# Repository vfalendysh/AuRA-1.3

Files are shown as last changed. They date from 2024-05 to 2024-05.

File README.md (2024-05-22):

# AuRA 1.3 Rotary Assist Film Developing Machine

## READ THIS FIRST
This project is the next iteration of the AuRA Film Developing Machine.
Original machine was introduced on the Kickstarter back in 2021.

https://www.kickstarter.com/projects/vfalendysh/aura-rotary-assist-film-developing-machine

v1.2 review by Alex Luyckx: https://www.youtube.com/watch?v=DZNfe24eHN0

I'm trying my best to keep this project alive for the benefit of the Film Photography community.

### PLEASE NOTE: 
- Everything provided AS IS, without any warranties.
- Non-commercial private use only. I reserve the right for the commercial distribution and use. 
- Zero liability - you do it at your own risk. I'm not liable for any damages related to this project.
- If you continue with this project it means that you read and agree with the above statements.

## LICENSE
Shared under Attribution-NonCommercial-ShareAlike 4.0 International License

https://creativecommons.org/licenses/by-nc-sa/4.0/deed.en

## PURCHASE YOUR AuRA
https://aurafd.company.site/

## Electronics Assembly Manual (WIP)
https://docs.google.com/document/d/1hErU2MmGirhdWFpWhWet4WLlM-BJHZemsq4ywI-r1ss/edit?usp=sharing

## Operations Manual
https://docs.google.com/document/d/11cLEZ-TlUOUsFuLOAkJhnijDMngBIQ9VhE78JiG_ncQ/edit?usp=sharing

## Questions?
Please ask here: https://www.facebook.com/groups/195994281887859

## Changes between 1.2 and 1.3
### Firmware
- Max dev. time increased to 90 minutes.
- Changed tanks captions in "Settings" menu.
- Enabled demo mode by default.

### Mechanical
- Main ball bearings are moved on the outside of the constaining bodies and now fixed on both sides.
- No need for retaining rings (no lathe work required) - replaced with shaft collars.
- Increased main case size a little bit for better access.
- Boards are now easily removable if needed - they are placed on the platform and fixed with 2 screws only.
- No USB port on a side (may add latter uppon request).

## Bill Of Materials
Most of the componets can be purchase on Amazon or AliExpress. 

https://docs.google.com/spreadsheets/d/1RUYtAMMg844CDN_oNOtQVQ9Nui_DjjbX51vlC8axlfM/edit?usp=sharing

Please let me know if something is missing from the BOM or you have sourcing questions.

## 3d Printer Settings
All parts should be printed with the following settings:
- 0.4mm nozzle
- 4 perimeters
- 0.2mm layer height
- 5 top/bottom shells
- 60% geroid infill
- PETG plastic
- Colors you like
  
Please make sure that your printer is calibrated and prints with the hight dimmensional accuracy.
If rollers do not fit - try to print one by one resizing it by 0.2% increment.

## Firmware
- Put folders / files from the "Firmware/libs" folder into your local Arduino/libraries folder.
- Choose "Arduino Nano" board in Arduino IDE. Sometimes you may need to choose "old bootloader" verstion of the board.
- Open "firmware/aura13.ino" file.
- Compile / upload to the board.

If you have binary size issues - make sure that U8G2 library has size optimizations turned on. 
Check for more here: https://github.com/olikraus/u8g2/wiki/u8g2optimization

## Electronics
Wire / assembly diagram - WIP.

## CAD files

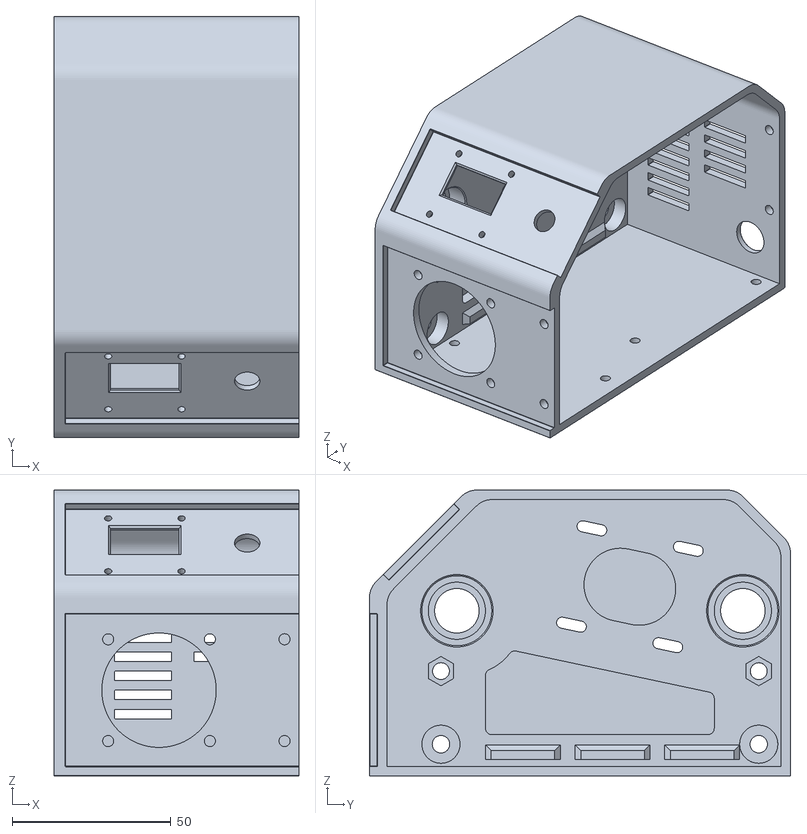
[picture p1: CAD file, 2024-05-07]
STL/Frame Main Case.stl
77.0 x 132.5 x 90.0

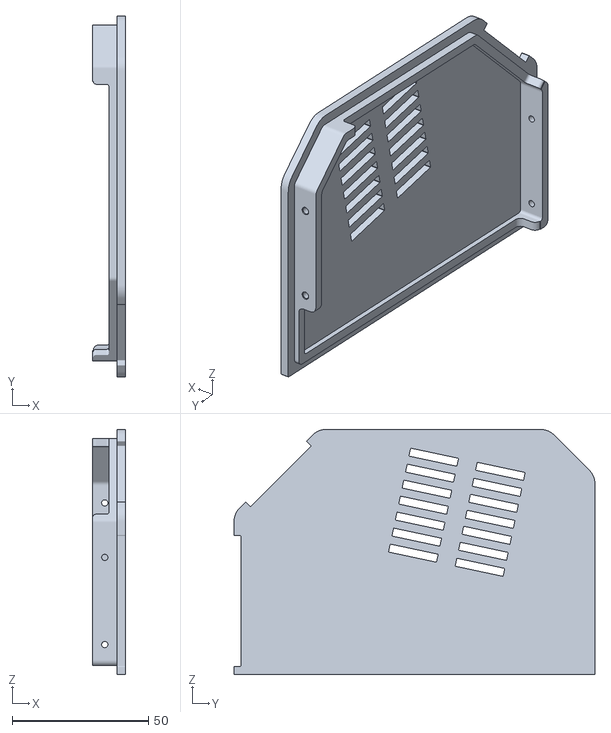
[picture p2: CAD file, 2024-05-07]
STL/Frame Main Case Side.stl
12.0 x 132.5 x 90.0

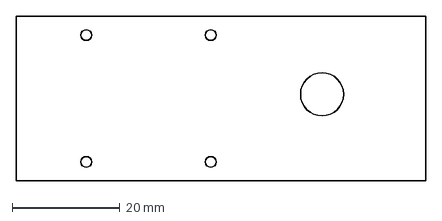
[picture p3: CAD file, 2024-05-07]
DXF/Screen Panel.dxf
76.0 x 30.5 mm

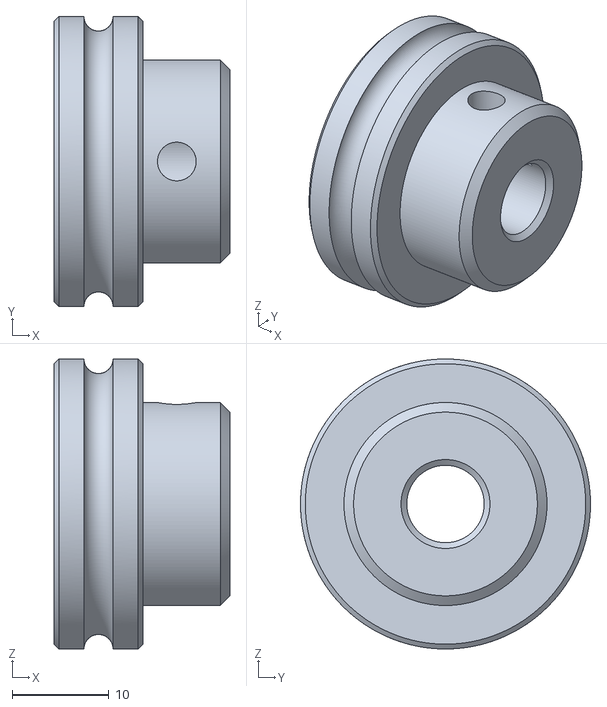
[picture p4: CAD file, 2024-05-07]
STL/Roller Soft Pad - 2x.stl
18.2 x 30.0 x 30.0

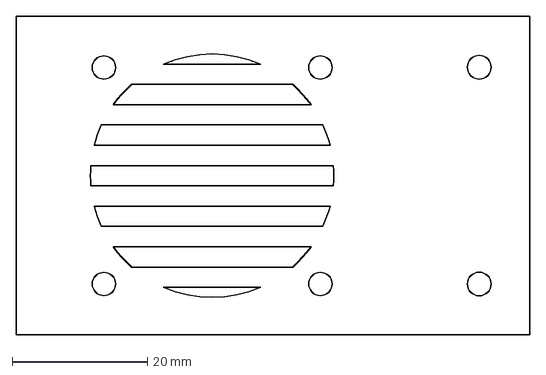
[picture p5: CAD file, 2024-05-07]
DXF/Fan Panel.dxf
76.0 x 47.1 mm

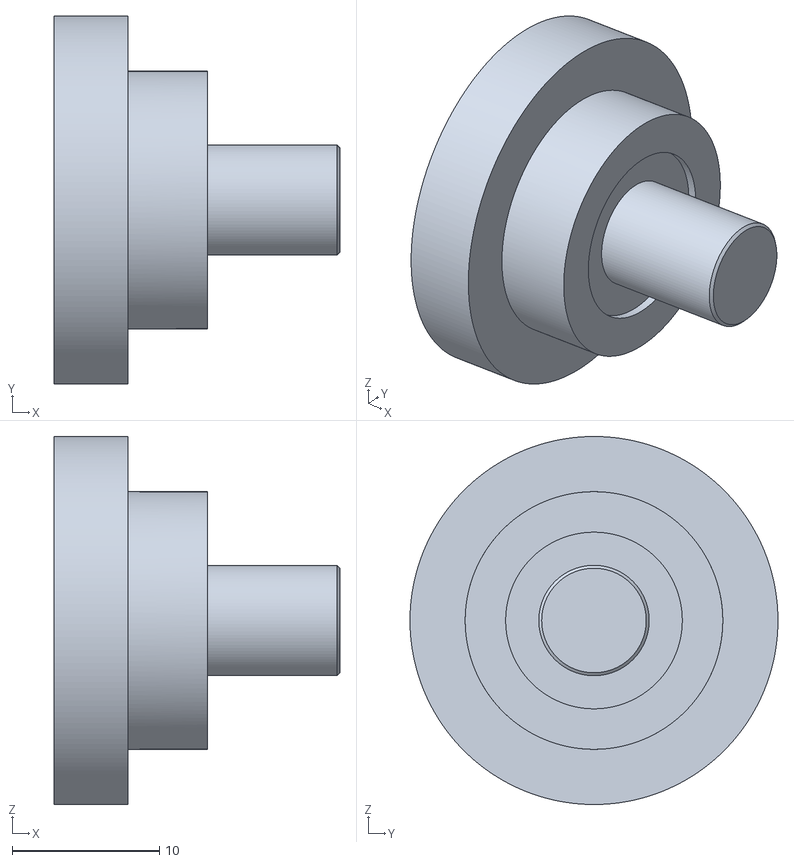
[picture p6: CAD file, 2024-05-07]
STL/Tool For Bearings.stl
19.4 x 25.0 x 25.0

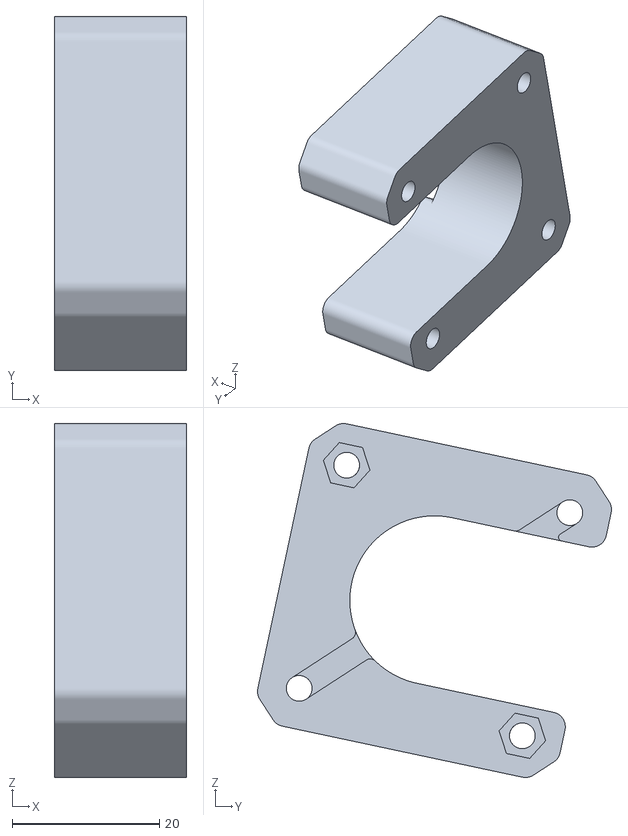
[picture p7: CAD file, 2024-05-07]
STL/Motor Base.stl
18.0 x 48.1 x 48.1

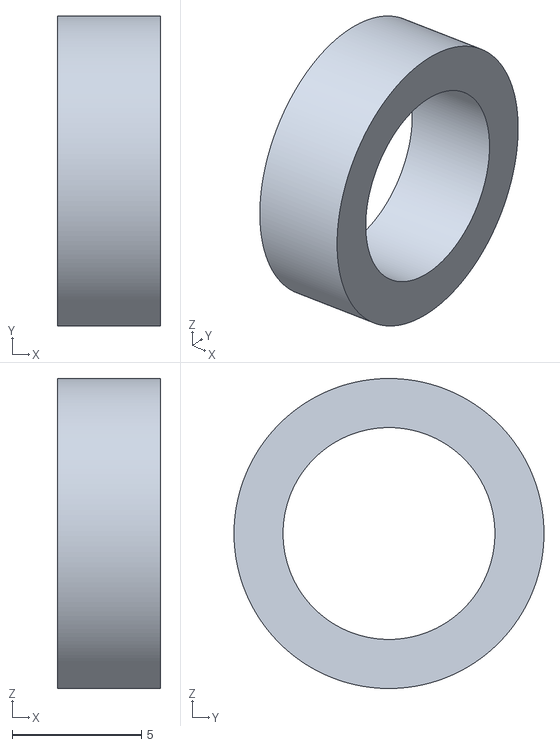
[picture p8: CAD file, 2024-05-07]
STL/Spacer 04mm - 2x.stl
4.00 x 12.0 x 12.0

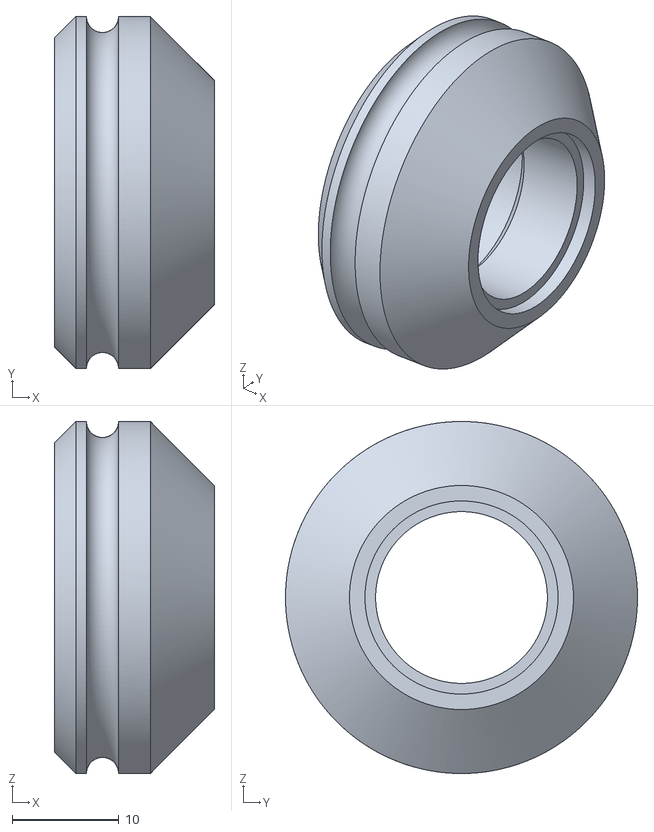
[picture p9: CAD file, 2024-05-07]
STL/Roller Paterson - 2x.stl
15.0 x 33.0 x 33.0

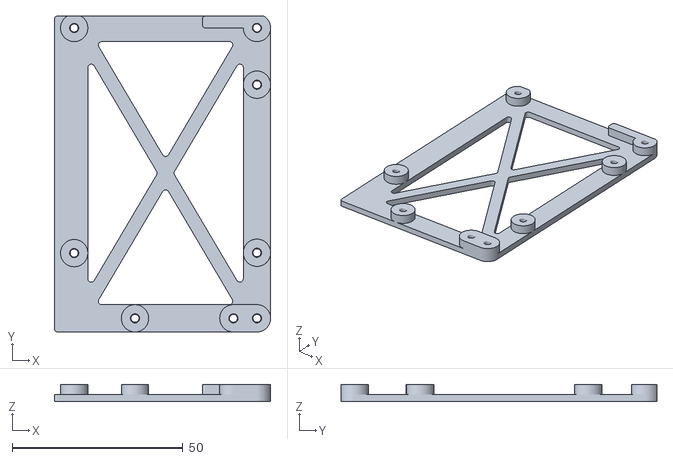
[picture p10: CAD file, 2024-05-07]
STL/Boards Base.stl
63.3 x 92.5 x 5.00

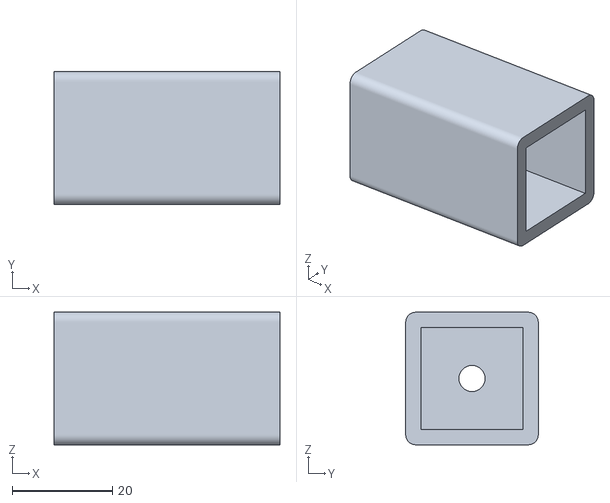
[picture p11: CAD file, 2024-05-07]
STL/Tool Extrusion Threading Guide.stl
45.0 x 26.4 x 26.4

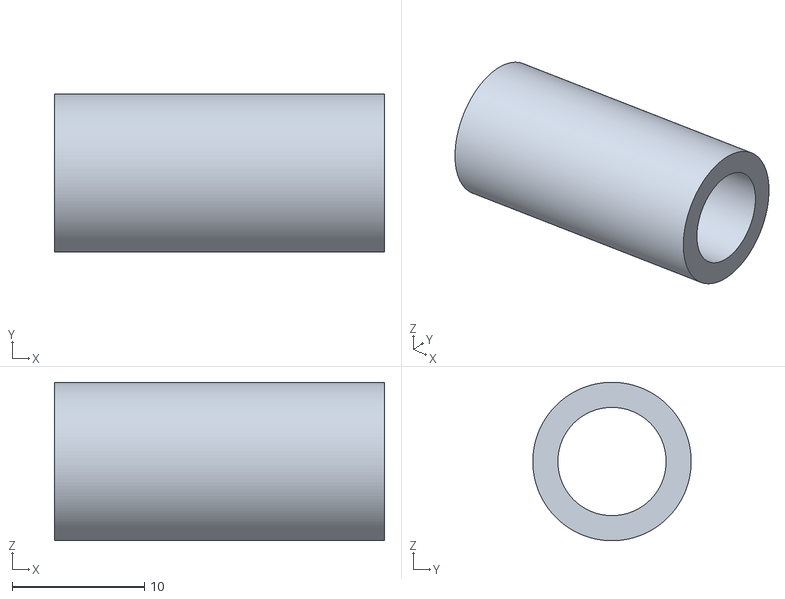
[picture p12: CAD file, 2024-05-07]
STL/Spacer 25mm - 2x.stl
25.0 x 12.0 x 12.0

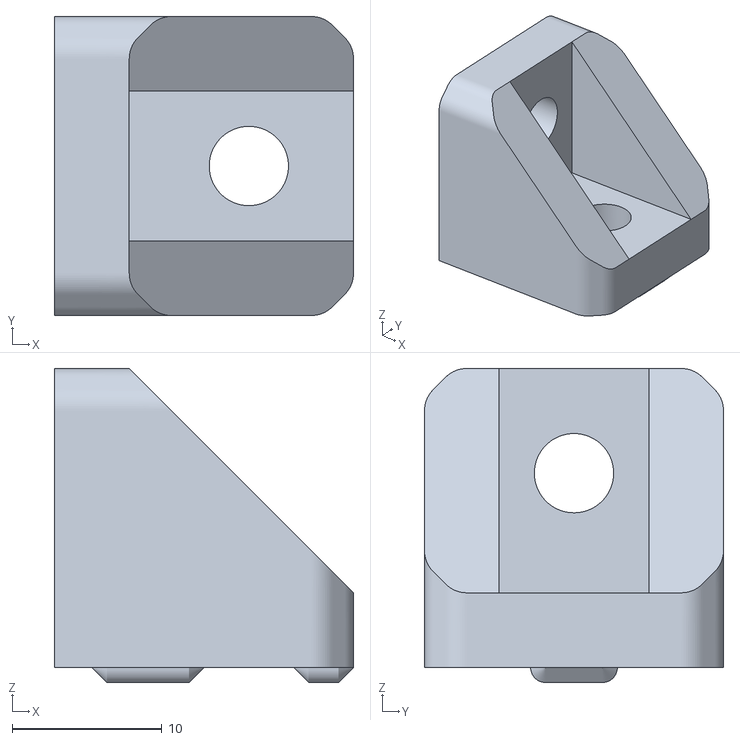
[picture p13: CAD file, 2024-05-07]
STL/Frame Corner Bracket - 4x.stl
20.0 x 20.0 x 21.0

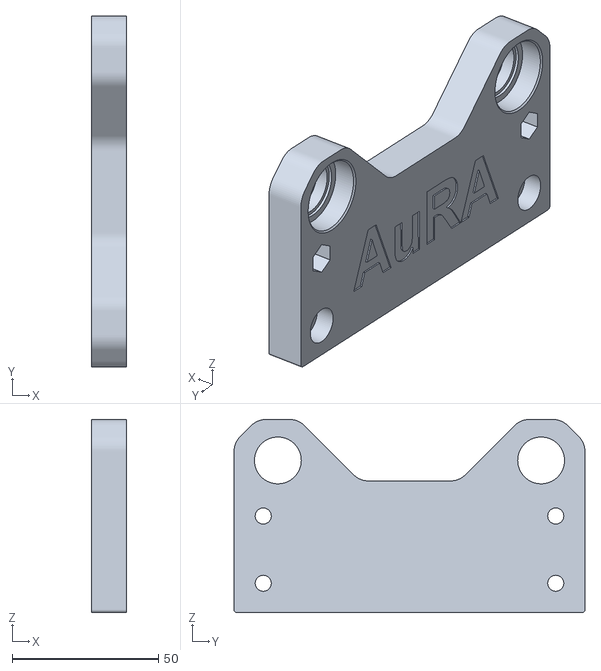
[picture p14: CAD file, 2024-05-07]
STL/Frame Drive Suppert Left.stl
12.0 x 120.0 x 66.0

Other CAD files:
STL/Spacer 12mm - 2x.stl
STL/Roller Jobo - 2x.stl
STL/Spacer 08mm - 2x.stl
STL/Roller Flat - 6x.stl
STL/Roller Nut Tool.stl

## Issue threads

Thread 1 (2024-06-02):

Missing Componenten Wiring Diagram

mherke, 2024-06-02:
Hello, are there any instructions on how to wire the electronic components? I found the documentation on GitHub, but it is still very incomplete.

...thanks for your support

Michael

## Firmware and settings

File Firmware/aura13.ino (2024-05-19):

#include <EEPROM.h>
#include <Rotary.h>
#include <U8g2lib.h>
#include "AccelStepper.h" 

// enables demo / test mode in settings menu. endlesly runs programs when enabled; 1 or 0
#define DEMO_AVAILABLE 1

// changes rotary encoder direction; 1 or -1
#define ENCODER_DIRECTION 1

// continuous must rotate counter clock when looking on a tank cap side
// set to -1 to invert or 1 to normal
#define MOTOR_DIRECTION -1

#include "Pins.h"
#include "Menus.h"

/**
 * Stepper
 */
AccelStepper stepper(1, PIN_MOTOR_STEP, PIN_MOTOR_DIR);

/**
 * Rotary encoder
 */
Rotary rotary = Rotary(PIN_ENC_A, PIN_ENC_B);

volatile boolean rotaryButtonUp = false;
volatile boolean rotaryButtonDown = false;
volatile boolean rotaryButtonPressed = false;
volatile boolean rotaryButtonLongPressed = false;
volatile boolean rotaryButtonWasPressed = false;
unsigned long rotaryButtonPressedMillis = 0;

/**
 * Machine state
 */
#define STATE_MENU 0
#define STATE_RUN 1
#define STATE_DONE 2
#define STATE_STOPPED 3

#define PROGRAMM_MODE_R1 MENU_ROOT_R1
#define PROGRAMM_MODE_R2 MENU_ROOT_R2
#define PROGRAMM_MODE_R3 MENU_ROOT_R3
#define PROGRAMM_MODE_R4 MENU_ROOT_R4
#define PROGRAMM_MODE_TIMER MENU_ROOT_TIMER

byte machineState = STATE_MENU;
bool presetSelected = false;

/**
 * Counters
 */
unsigned int finishedCount = 0; 
unsigned int interruptedCount = 0;

/**
 * Settings
 */
#define EEPROM_SETTINGS_SAVED 0
#define EEPROM_SETTINGS_SOUND 1
#define EEPROM_SETTINGS_TANK 2
#define EEPROM_SETTINGS_FINISHED_BYTE1 3
#define EEPROM_SETTINGS_FINISHED_BYTE0 4
#define EEPROM_SETTINGS_INTERRUPTED_BYTE1 5
#define EEPROM_SETTINGS_INTERRUPTED_BYTE0 6
#if (DEMO_AVAILABLE == 1)
  #define EEPROM_SETTINGS_DEMO 7
#endif  

// Preset settings
#define EEPROM_SETTINGS_PRESETS_OFFSET 10

#define PRESET_MODE 0
#define PRESET_MINUTES 1
#define PRESET_SECONDS 2
#define PRESET_SPEED 3

#define MAX_MINUTES 90

volatile byte presets[PRESETS_COUNT][PRESETS_SETTINGS_COUNT] = {
  {0, 10, 0, 50},
  {0, 10, 0, 50},
  {0, 10, 0, 50},
  {0, 10, 0, 50},
  {0, 10, 0, 50},
};

/**
 * Tanks
 */
#define TANK_MODEL_COUNT 3
#define TANK_J1500 0
#define TANK_J2500 1
#define TANK_P4 2

/**
 * Sound
 */
byte settingsSound = 1;
byte settingsTank = TANK_J1500;

/**
 * Demo / test mode
 */
#if (DEMO_AVAILABLE == 1)
  byte settingsDemo = 0;
#endif  

/**
 * Menus
 */
byte menuMode = MENU_MODE_ROOT;
int8_t menuPosition = 0;
int8_t menuPresetsPosition = 0;
int8_t menuSettingsPosition = 0;
int8_t menuSettingsPresetsPosition = 0;
byte programmMode = 0;

/**
 * Programm times in seconds
 */
int programmDurationSeconds = 300;
int programmTimeSeconds = 0;
int programmTimeLeftSeconds = programmDurationSeconds;

/**
 * Motor vars
 */
bool runMotor = false;
bool runMotorBackwards = false;
int  runMotorBackwardsSwitchTime = 0;
bool motorAccelerating = false;
bool slowDown = false;

#define MOTOR_SPEEDS_COUNT 12
byte motorSpeedIndex = 9;
byte motorRPMs[MOTOR_SPEEDS_COUNT] = {5, 10, 15, 20, 25, 30, 35, 40, 45, 50, 60, 75};

float motorSpeedMultipliers[TANK_MODEL_COUNT][MOTOR_SPEEDS_COUNT] = {
  // Jobo 1500
  {19, 19, 19, 19.25, 19.25, 19.5, 19.5, 19.5, 19.75, 20.0, 20.25, 20.5},

  // Jobo 2500
  {27, 27, 27, 27.34, 27.34, 27.69, 27.69, 27.69, 28.00, 28.4, 28.75, 29.1},

  // Paterson 4
  {21.0, 21.0, 21.5, 21.8, 22.0, 22.2, 22.2, 22.5, 22.7, 23.0, 23.0, 23.0}
};

int motorMaxSpeed;
int motorTargetSpeed;
float motorCurrentSpeed = 0;

float motorAcceleration = 0.2;
float motorDeceleration = 0.16;

/**
 * Screen
 */
U8G2_SSD1306_128X64_NONAME_2_HW_I2C u8g2(U8G2_R0, PIN_OLED_CLK, PIN_OLED_DAT);

/**
 * Setup
 */
void setup() {
  /**
   * Settings from memory
   */
  if (EEPROM.read(EEPROM_SETTINGS_SAVED) == 1) {
    settingsSound = EEPROM.read(EEPROM_SETTINGS_SOUND);
    
    #if (DEMO_AVAILABLE == 1)
      settingsDemo = EEPROM.read(EEPROM_SETTINGS_DEMO);     
    #endif
      
    settingsTank = EEPROM.read(EEPROM_SETTINGS_TANK);

    finishedCount = EEPROM.read(EEPROM_SETTINGS_FINISHED_BYTE1) * 256 + EEPROM.read(EEPROM_SETTINGS_FINISHED_BYTE0);
    interruptedCount = EEPROM.read(EEPROM_SETTINGS_INTERRUPTED_BYTE1) * 256 + EEPROM.read(EEPROM_SETTINGS_INTERRUPTED_BYTE0);

    for (byte i = 0; i < PRESETS_COUNT; i++) {
      presets[i][PRESET_MODE] = EEPROM.read(EEPROM_SETTINGS_PRESETS_OFFSET + i * PRESETS_SETTINGS_COUNT + PRESET_MODE);
      presets[i][PRESET_MINUTES] = EEPROM.read(EEPROM_SETTINGS_PRESETS_OFFSET + i * PRESETS_SETTINGS_COUNT + PRESET_MINUTES);
      presets[i][PRESET_SECONDS] = EEPROM.read(EEPROM_SETTINGS_PRESETS_OFFSET + i * PRESETS_SETTINGS_COUNT + PRESET_SECONDS);
      presets[i][PRESET_SPEED] = EEPROM.read(EEPROM_SETTINGS_PRESETS_OFFSET + i * PRESETS_SETTINGS_COUNT + PRESET_SPEED);
    }
  }

  // check settings
  if (settingsSound > 1) settingsSound = 1;
  
  #if (DEMO_AVAILABLE == 1)
    if (settingsDemo > 1) settingsDemo = 1;
  #endif
  
  if (settingsTank >= TANK_MODEL_COUNT) settingsTank = TANK_J1500;
  if (finishedCount > 65530) finishedCount = 0;
  if (interruptedCount == 65530) interruptedCount = 0;
  
  for (byte i = 0; i < PRESETS_COUNT; i++) {
    if (presets[i][PRESET_MODE] > 2) presets[i][PRESET_MODE] = 0;
    if (presets[i][PRESET_MINUTES] > MAX_MINUTES) {
      presets[i][PRESET_MINUTES] = 10;
      presets[i][PRESET_SECONDS] = 0;
    }
    if (presets[i][PRESET_SECONDS] >= 60) presets[i][PRESET_SECONDS] = 0;

    if (presets[i][PRESET_MINUTES] * MAX_MINUTES + presets[i][PRESET_SECONDS] < 60) {
      presets[i][PRESET_MINUTES] = 10;
      presets[i][PRESET_SECONDS] = 0;
    }

    if (presets[i][PRESET_SPEED] >= MOTOR_SPEEDS_COUNT) presets[i][PRESET_SPEED] = motorSpeedIndex;
  }

  motorMaxSpeed = 3000;
  motorTargetSpeed = motorRPMs[motorSpeedIndex] * motorSpeedMultipliers[settingsTank][motorSpeedIndex];

  /**
   * Stepper setup
   */
  stepper.setMaxSpeed(motorMaxSpeed);
  stepper.setEnablePin(PIN_MOTOR_EN);
  stepper.setPinsInverted(false, false, true);

  /**
   * Buzzer
   */
  pinMode(PIN_BUZZER, OUTPUT);

  /**
   * Fan 
   */
  pinMode(PIN_FAN, OUTPUT);
  
  /**
   * Rotary encoder
   */
  pinMode(PIN_ENC_C, INPUT_PULLUP);

  u8g2.begin();
  u8g2.setFontPosTop();
  
  digitalWrite(PIN_FAN, HIGH);
  displayIntro();
  delay(2500);  
  digitalWrite(PIN_FAN, LOW);
  
  updateScreen();

  /**
   * Time interruprs
   */
  // TIMER 1 for interrupt frequency 16000 Hz:
  cli(); // stop interrupts
  TCCR1A = 0; // set entire TCCR1A register to 0
  TCCR1B = 0; // same for TCCR1B
  TCNT1  = 0; // initialize counter value to 0
  // set compare match register for 16000 Hz increments
  OCR1A = 999; // = 16000000 / (1 * 16000) - 1 (must be <65536)
  // turn on CTC mode
  TCCR1B |= (1 << WGM12);
  // Set CS12, CS11 and CS10 bits for 1 prescaler
  TCCR1B |= (0 << CS12) | (0 << CS11) | (1 << CS10);
  // enable timer compare interrupt
  TIMSK1 |= (1 << OCIE1A);
  sei(); // allow interrupts
}

/**
 * Runs motor on timer interrupt
 * timer1 interrupt 8kHz toggles pin 9
 */
ISR(TIMER1_COMPA_vect){
  //generates pulse wave of frequency 8kHz/2 = 4kHz (takes two cycles for full wave- toggle high then toggle low)
  if (machineState == STATE_RUN && runMotor) {
    stepper.runSpeed();
  }
}

/**
 * Main loop
 */
void loop() {

  if (machineState == STATE_MENU) {
    handleRotaryEncoder();
  
    if (rotaryButtonPressed) {
      handleMenuSelectActions();
      if (machineState == STATE_MENU) updateScreen();
      rotaryButtonPressed = false;
      delay(200);
    } else if (rotaryButtonLongPressed) {
      handleMenuBackActions();
      if (machineState == STATE_MENU) updateScreen();
      rotaryButtonLongPressed = false;
      delay(200);
    } else if (rotaryButtonUp || rotaryButtonDown) {
      handleMenuScrollActions();
      updateScreen();
      rotaryButtonUp = rotaryButtonDown = false;
    }
   
  } else if (machineState == STATE_RUN) {
    runProgramm();
  } else if (machineState == STATE_DONE || machineState == STATE_STOPPED) {
    
    handleRotaryEncoder();
    
    if (rotaryButtonPressed || rotaryButtonLongPressed || rotaryButtonUp || rotaryButtonDown) {
      if (presetSelected) {
        machineState = STATE_MENU;
        menuMode = MENU_MODE_PRESETS;
        //menuPresetsPosition++;
        //if (menuPresetsPosition >= PRESETS_COUNT) menuPresetsPosition = 0;
      } else {
        machineState = STATE_MENU;
        menuMode = MENU_MODE_ROOT;
      }
      updateScreen();
      rotaryButtonPressed = rotaryButtonLongPressed = rotaryButtonUp = rotaryButtonDown = false;
      delay(200);
    }
  }
}

/**
 * Get speed by index
 */
int getSpeedByIndex(byte i) {
  return motorRPMs[i] * motorSpeedMultipliers[settingsTank][i];
}

/**
 * Get deceleration coeficient by index
 */
float getAccelerationByIndex(byte i) {
  return motorRPMs[i] / (settingsTank == TANK_J1500 ? 175.0 : (settingsTank == TANK_J2500 ? 125.0 : 150.0)); // bigger number - smaller steps, slower acceleration
}

/**
 * Get deceleration coeficient by index
 */
float getDecelerationByIndex(byte i) {
  return motorRPMs[i] / (settingsTank == TANK_J1500 ? 200.0 : (settingsTank == TANK_J2500 ? 125.0 : 150.0)); // bigger number - smaller steps, slower deceleration
}

/**
 * Beep
 */
void beep(int d) {
  tone(PIN_BUZZER, 3520);
  delay(d);
  noTone(PIN_BUZZER);
}

/**
 * Run programm
 */
void runProgramm() {
  unsigned long programmStartMillis = millis();
  unsigned long programmLeftMillis = programmDurationSeconds * 1000L;
  unsigned long programmEndMillis = programmStartMillis + programmLeftMillis;
  unsigned long lastScreenUpdateSecond;

  runMotorBackwards = false;
  runMotorBackwardsSwitchTime = 0;
  runMotor = false;
  slowDown = false;
  programmTimeSeconds = 0;
  lastScreenUpdateSecond = 1;

  programmTimeLeftSeconds = programmDurationSeconds;
 
  if (programmMode != PROGRAMM_MODE_TIMER) {

    if ((settingsTank == TANK_J2500) && (motorSpeedIndex > MOTOR_SPEEDS_COUNT - 3)) motorSpeedIndex = MOTOR_SPEEDS_COUNT - 3; // 50 max
    
    motorCurrentSpeed = 0;
    motorTargetSpeed = getSpeedByIndex(motorSpeedIndex);
    stepper.enableOutputs();
    setMotorState();

    // run fun only when motor is moving
    digitalWrite(PIN_FAN, HIGH);
  }

  updateScreen();
  
  for (;;) {
    
    unsigned long currentMillis = millis();

    programmTimeLeftSeconds = programmLeftMillis / 1000L;
    programmTimeSeconds = programmDurationSeconds - programmTimeLeftSeconds;
    
    if (currentMillis > programmEndMillis) {
      
      if (programmMode != PROGRAMM_MODE_TIMER) {
        runMotor = false;
        digitalWrite(PIN_FAN, LOW);
        stepper.disableOutputs();
      }

      finishedCount++;
      EEPROM.write(EEPROM_SETTINGS_FINISHED_BYTE1, finishedCount >> 8);
      EEPROM.write(EEPROM_SETTINGS_FINISHED_BYTE0, finishedCount % 256);
      
      machineState = STATE_DONE;
      updateScreen();

      if (settingsSound == 1) {
        beep(1000);
        delay(100);
        beep(1000);
      }

      #if (DEMO_AVAILABLE == 1)
        if (settingsDemo == 1) {
          delay(1000);
          machineState = STATE_RUN;
          programmTimeLeftSeconds = programmDurationSeconds;
          programmTimeSeconds = 0;
          programmMode++;
          if (programmMode >= PROGRAMM_MODE_TIMER) {
            programmMode = PROGRAMM_MODE_R1; 
          }
          updateScreen();
        }  
      #endif   
      
      break;
    }
    
    programmLeftMillis = programmEndMillis - currentMillis;

    handleRotaryEncoder();

    if (programmMode != PROGRAMM_MODE_TIMER) {
      /**
       * Increase RPM
       */
      if (rotaryButtonUp) {
        if (motorSpeedIndex < MOTOR_SPEEDS_COUNT - 1) {
          motorSpeedIndex += 1;

          if ((settingsTank == TANK_J2500) && (motorSpeedIndex > MOTOR_SPEEDS_COUNT - 3)) motorSpeedIndex = MOTOR_SPEEDS_COUNT - 3; // 50 max
          
          motorTargetSpeed = getSpeedByIndex(motorSpeedIndex);
          updateScreen();
        }
        rotaryButtonUp = false;
      }
  
      /**
       * Decrease RPM
       */
      if (rotaryButtonDown) {
        if (motorSpeedIndex > 0) {
          motorSpeedIndex -= 1;
          motorTargetSpeed = getSpeedByIndex(motorSpeedIndex);
          updateScreen();
        }
        rotaryButtonDown = false;
      }
  
      setMotorState();
    }

    /**
     * Stop programm
     */
    if (rotaryButtonLongPressed) {
      runMotor = false;
      digitalWrite(PIN_FAN, LOW);
      stepper.disableOutputs();
      machineState = STATE_STOPPED;
      
      interruptedCount++;
      EEPROM.write(EEPROM_SETTINGS_INTERRUPTED_BYTE1, interruptedCount >> 8);
      EEPROM.write(EEPROM_SETTINGS_INTERRUPTED_BYTE0, interruptedCount % 256);
      
      updateScreen();
      rotaryButtonLongPressed = false;
      delay(200);
      break; 
    }

    /**
     * Check programm times
     */
    if (programmTimeSeconds != lastScreenUpdateSecond) {
      
      updateScreen();
      
      lastScreenUpdateSecond = programmTimeSeconds;

      if (settingsSound == 1) {
        if (programmTimeLeftSeconds == 60) {
          beep(100);
        } else if (programmTimeLeftSeconds == 30) {
          beep(100); delay(100); beep(100);
        }
      }
    }
  }
}

void setMotorStateAccelR2R3R4() {
  if (motorCurrentSpeed < motorTargetSpeed) {
    motorCurrentSpeed += getAccelerationByIndex(motorSpeedIndex);
    if (motorCurrentSpeed > motorTargetSpeed) motorCurrentSpeed = motorTargetSpeed;
  } else if (motorCurrentSpeed > motorTargetSpeed) {
    motorCurrentSpeed -= getDecelerationByIndex(motorSpeedIndex);
    if (motorCurrentSpeed < 0) motorCurrentSpeed = 0;
  }
}

/**
 * Set motor state
 */
void setMotorState() {

  int sec = programmTimeSeconds % 60;
  
  if (programmTimeLeftSeconds < 2) {
    slowDown = true;
    motorTargetSpeed = 0;
  }

  switch (programmMode) {
    /**
     * Easy
     */
    case PROGRAMM_MODE_R1: {
      byte mod = sec % 30;
      if (programmTimeSeconds <= 30) {
        // fast first 30 seconds
        motorTargetSpeed = getSpeedByIndex(motorSpeedIndex);
      } else {
        motorTargetSpeed = getSpeedByIndex(mod >= 25 ? motorSpeedIndex : motorSpeedIndex / 5);
          if (mod == 24) motorTargetSpeed = 0;
          if ((mod == 25) && (programmTimeSeconds - runMotorBackwardsSwitchTime > 0)) {
            runMotorBackwards = !runMotorBackwards;
            runMotorBackwardsSwitchTime = programmTimeSeconds;
          }
      }
      
      if (motorCurrentSpeed < motorTargetSpeed) {
        // accelerate
        motorCurrentSpeed += getAccelerationByIndex(motorSpeedIndex);
        if (motorCurrentSpeed > motorTargetSpeed) motorCurrentSpeed = motorTargetSpeed;
      } else if (motorCurrentSpeed > motorTargetSpeed && motorCurrentSpeed > 0) {
        // decelerate
        motorCurrentSpeed -= motorTargetSpeed == 0 ? getDecelerationByIndex(0) : getDecelerationByIndex(motorSpeedIndex);
        if (motorCurrentSpeed < 0) motorCurrentSpeed = 0;
      }

      stepper.setSpeed((runMotorBackwards ? -1 : 1) * motorCurrentSpeed * MOTOR_DIRECTION);
      
      runMotor = true;
        
      break;
    }

    /**
     * Continuous
     */
    case PROGRAMM_MODE_R2: {
     
      setMotorStateAccelR2R3R4();
      stepper.setSpeed(motorCurrentSpeed * MOTOR_DIRECTION);
      
      runMotor = true;
        
      break;
    }

    /**
     * Oscilation 1:1
     */
    case PROGRAMM_MODE_R3: {
      byte mod = sec % 15;

      motorTargetSpeed = slowDown ? 0 : (mod < 8 ? (mod > 6 ? 0 : getSpeedByIndex(motorSpeedIndex)) : (mod > 13 ? 0 : getSpeedByIndex(motorSpeedIndex)));
      
      setMotorStateAccelR2R3R4();
      stepper.setSpeed((mod < 8 ? motorCurrentSpeed : - motorCurrentSpeed) * MOTOR_DIRECTION);
      
      runMotor = true;
            
      break;
    }
    
    /**
     * Progress 1:5
     */
    case PROGRAMM_MODE_R4: {
      byte mod = sec % 10;

      motorTargetSpeed = slowDown ? 0 : (mod < 7 ? (mod > 5 ? 0 : getSpeedByIndex(motorSpeedIndex)) : (mod > 8 ? 0 : getSpeedByIndex(motorSpeedIndex)));
     
      setMotorStateAccelR2R3R4(); 
      stepper.setSpeed((mod < 7 ? motorCurrentSpeed : - motorCurrentSpeed) * MOTOR_DIRECTION);
      
      runMotor = true;
            
      break;
    }
  }
}

/**
 * Handle rotary encoder
 */
void handleRotaryEncoder() {
  
  unsigned char result = rotary.process();

  if (result == DIR_CW) {
     rotaryButtonDown = true;
  } else if (result == DIR_CCW) {
     rotaryButtonUp = true;
  }
  
  if (!digitalRead(PIN_ENC_C)) {
    if (!rotaryButtonWasPressed) {
      rotaryButtonWasPressed = true;
      rotaryButtonPressedMillis = millis();
      unsigned long rotarryButtonPressedDuration = millis() - rotaryButtonPressedMillis;
      if (rotarryButtonPressedDuration > 500) {
        rotaryButtonLongPressed = true;
      }
    }
  } else {
    if (rotaryButtonWasPressed) {
      unsigned long rotarryButtonPressedDuration = millis() - rotaryButtonPressedMillis;
      if (rotarryButtonPressedDuration > 500) {
        rotaryButtonLongPressed = true;
      } else {
        rotaryButtonPressed = true;
      }

      rotaryButtonWasPressed = false;
    }
  }
}
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

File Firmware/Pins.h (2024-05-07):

/**
 * Stepper motor
 */
#define PIN_MOTOR_EN 8 
#define PIN_MOTOR_STEP 7
#define PIN_MOTOR_DIR 4

#define PIN_FAN_PWM A3

/**
 * Buzzer
 */
#define PIN_BUZZER 12

/**
 * Fan
 */
#define PIN_FAN A3

/**
 * Rotary encoder
 */
#if ENCODER_DIRECTION == 1
  #define PIN_ENC_A 9
  #define PIN_ENC_B 10
#else
  #define PIN_ENC_A 10
  #define PIN_ENC_B 9
#endif  

#define PIN_ENC_C 11

/**
 * Oled screen
 */
#define PIN_OLED_CLK 5
#define PIN_OLED_DAT 4
#define PIN_OLED_CS 16

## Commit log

2024-05-07 Innitial commit
    [Boards Base.stl, Fan Panel.dxf, Frame Corner Bracket - 4x.stl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]
2024-05-19 Fixed presets 1.5 multiplication error
    [aura13.ino]
